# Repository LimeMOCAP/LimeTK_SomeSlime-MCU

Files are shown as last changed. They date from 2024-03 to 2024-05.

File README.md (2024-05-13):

# LimeTK_SomeSlime-MCU

LimeTK_SomeSlime 是 SlimeVR 的一套硬件设计，但只有 PCB 部分没有外壳。

它是 LimeTK 项目中产生的一个副产品，它的上游是 `LimeTK_Soda-MCU v1.2` 但由于 ESP-IDF 对新手过于的不友好导致它的固件编写停滞了很久很久。\
SomeSlime-MCU 顾名思义（指 Slime）是一个 SlimeVR 的硬件设计方案，所以并不使用自定义的固件或者特别的 SlimeVR 固件分支，照常修改配置文件即可

也是因此这个项目有着不少 Soda 上残存的怨念，所以它的版本号永远都会以 `v0.` 开头

## 硬件设计理念

它们的理念都是尽可能的实现：最小的空间占用，以及可管控的电池安全

对此 LimeTK_SomeSlime 使用了 ESP32-C3 模组而非完整的开发板作为通讯模块。\
对于电池... 自己插根 JST-PH 的线上去，我不管啦（坏笑）。而且如果你想的话，板子上有三个接口可供菊花链哦

## PCB 制造

下载发布版本中的 `.zip` 或者带有 `gerber` 字样的压缩文件并提交到制造商即可，或者也可以检出对应的 git 标签用 kicad 打开项目从头导出一份 gerber 文件。\
至于导出标准嘛...

## 固件配置

文档位于: [docs/Firmware-example.md](docs/Firmware-example.md)

## 共享许可

硬件设计: CERN-OHL-W v2\
CERN Open Hardware Licence - weakly reciprocal - version 2

文档许可: CC BY 4.0\
知识共享许可协议 - 署名 4.0 国际

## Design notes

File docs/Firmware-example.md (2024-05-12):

# Firmware-example

LimeTK_SomeSlime 完全使用 SlimeVR 的追踪器固件，因此该文档仅提供需要修改的部分代码片段

注意：所有**配置仅作参考**，均需要随着 SlimeVR 追踪器固件的变更而随机应变

最后更新时 SomeSlime 硬件版本为: `v0.1`

## File: platformio.ini

```ini
[env:esp32-c3]
platform = espressif32 @ 6.1.0
build_flags =
 ${env.build_flags}
 -DESP32C3
board = esp32-c3-devkitm-1
```

## File: defines.h

```c
#define IMU IMU_BMI160
#define SECOND_IMU IMU
#define BOARD BOARD_CUSTOM
#define IMU_ROTATION DEG_270
#define SECOND_IMU_ROTATION DEG_270
```

> SomeSlime 并没有第二个追踪器，所以可以随便填写角度

```c
#elif BOARD == BOARD_CUSTOM
  // Define pins by the examples above
  #define PIN_IMU_SDA 0
  #define PIN_IMU_SCL 1
  #define PIN_IMU_INT NULL
  #define PIN_IMU_INT_2 NULL
  #define PIN_BATTERY_LEVEL NULL
  #define LED_PIN 7
  #define LED_INVERTED false
```

此处的引脚编号就是芯片中 GPIO 的编号。\
或许是因为 ESP32 的所有引脚都可以是 GPIO 吧，连类似 D0 这种格式都不用了

> 我也不知道 NULL 会对固件内部产生什么影响，但我总不能空着吧\
> It just works.

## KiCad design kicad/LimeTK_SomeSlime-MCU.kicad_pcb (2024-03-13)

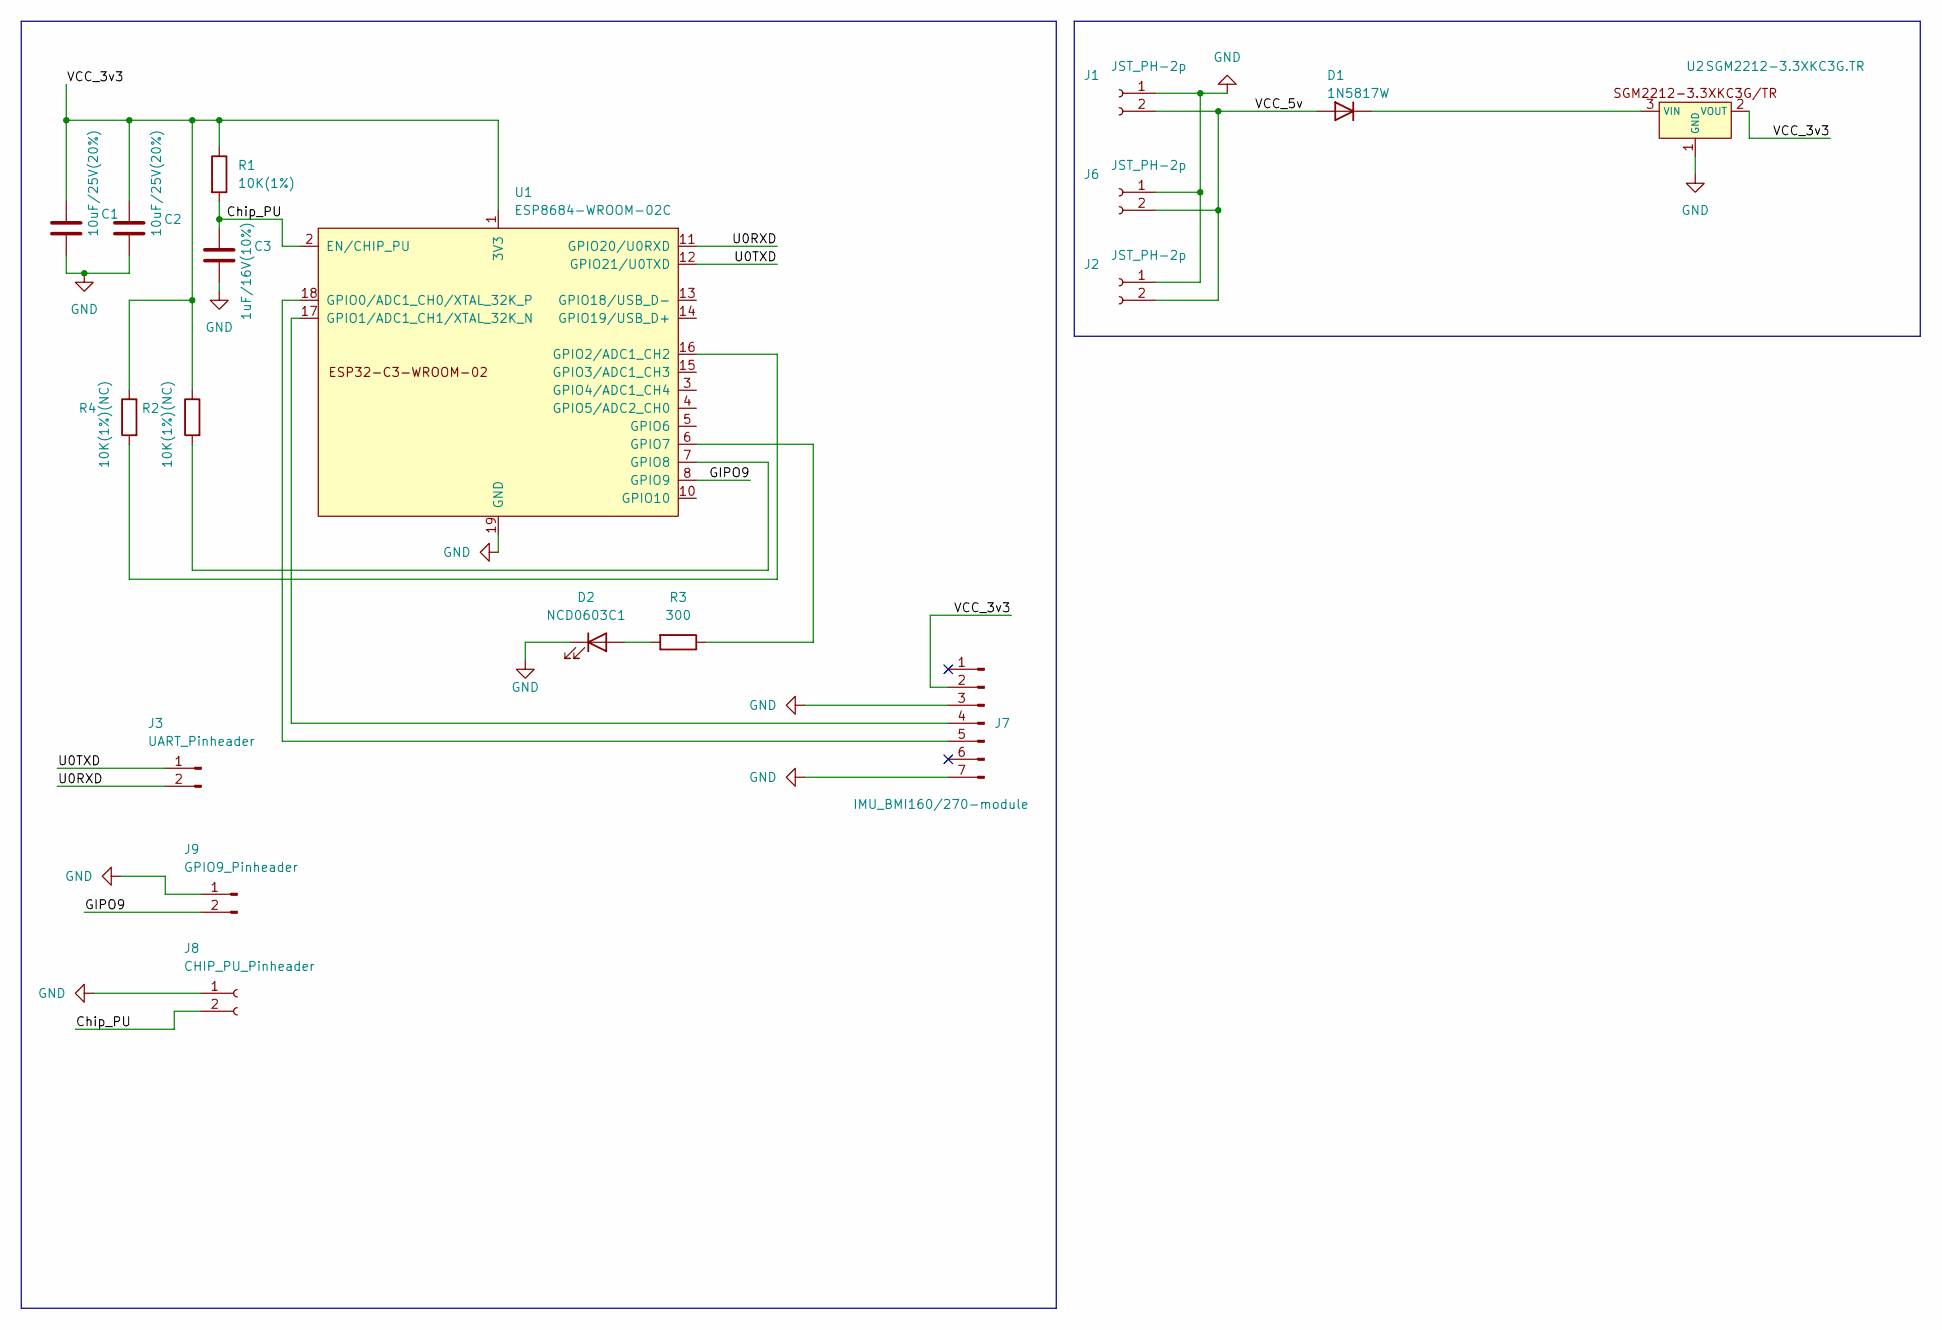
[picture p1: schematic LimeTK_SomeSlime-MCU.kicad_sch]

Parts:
C1, C2: 10uF/25V(20%); R_0603_1608Metric_Pad0.98x0.95mm_HandSolder
C3: 1uF/16V(10%); R_0603_1608Metric_Pad0.98x0.95mm_HandSolder
D1: 1N5817W; D_SOD-123
D2: NCD0603C1; LED_0603_1608Metric_Pad1.05x0.95mm_HandSolder
J1, J2, J6: JST_PH-2p; JST_PH_B2B-PH-K_1x02_P2.00mm_Vertical
J3: UART_Pinheader; PinHeader_1x02_P2.54mm_Vertical
J7: IMU_BMI160/270-module; PinHeader_1x07_P2.54mm_Vertical
J8: CHIP_PU_Pinheader; PinHeader_1x02_P2.54mm_Vertical
J9: GPIO9_Pinheader; PinHeader_1x02_P2.54mm_Vertical
R1: 10K(1%); R_0603_1608Metric_Pad0.98x0.95mm_HandSolder
R2, R4: 10K(1%)(NC); R_0603_1608Metric_Pad0.98x0.95mm_HandSolder
R3: 300; R_0603_1608Metric_Pad0.98x0.95mm_HandSolder
U1: ESP8684-WROOM-02C; ESP32-C3-WROOM-02
U2: SGM2212-3.3XKC3G.TR

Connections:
/Chip_PU: C3.1, J8.2, R1.2, U1.2 (EN/CHIP_PU)
/GIPO9: J9.2, U1.8 (GPIO9)
/U0RXD: J3.2, U1.11 (GPIO20/U0RXD)
/U0TXD: J3.1, U1.12 (GPIO21/U0TXD)
/VCC_3v3: C1.1, C2.1, J7.2, R1.1, R2.1, R4.1, U1.1 (3V3), U2.2 (VOUT)
/VCC_5v: D1.2 (A), J1.2, J2.2, J6.2
GND: C1.2, C2.2, C3.2, D2.1 (K), J1.1, J2.1, J6.1, J7.3, J7.7, J8.1, J9.1, U1.9 (GND), U1.19 (GND), U2.1 (GND)
unnamed: D1.1 (K), U2.3 (VIN)
unnamed: D2.2 (A), R3.2
unnamed: J7.4, U1.17 (GPIO1/ADC1_CH1/XTAL_32K_N)
unnamed: J7.5, U1.18 (GPIO0/ADC1_CH0/XTAL_32K_P)
unnamed: R4.2, U1.16 (GPIO2/ADC1_CH2)
unnamed: R3.1, U1.6 (GPIO7)
unnamed: R2.2, U1.7 (GPIO8)

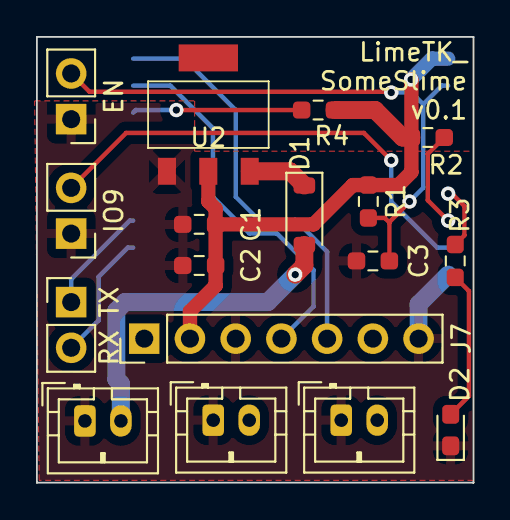
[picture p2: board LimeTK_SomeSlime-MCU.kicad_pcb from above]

Board: 2 copper layers, 24.3 x 24.8 mm, 18 parts (1 on the bottom side), 14 nets.

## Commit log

2024-03-13 初始化储存库
2024-03-13 v0.1 Released
    [LimeVR_Soda.kicad_pcb, LimeVR_Soda.kicad_sch]
2024-03-13 更正文件名
    都是基于 soda 改得嘛，忘改名字了
    [LimeTK_SomeSlime-MCU.kicad_pcb, LimeTK_SomeSlime-MCU.kicad_sch]
2024-05-12 修改目录名
    [LimeTK_SomeSlime-MCU.kicad_pcb, LimeTK_SomeSlime-MCU.kicad_sch]
2024-05-12 添加固件参考文档
2024-05-12 完善文档
2024-05-12 修改许可描述
2024-05-12 修改文档
2024-05-13 更新自述文件
